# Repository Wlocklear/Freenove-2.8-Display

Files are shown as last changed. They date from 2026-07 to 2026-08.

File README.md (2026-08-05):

# Freenove ESP32-S3 2.8" (CYD) Display Case — v1.0

A closed, tilted desktop enclosure for the Freenove ESP32-S3 2.8" capacitive-touch
display (ESP32-2432S028R "CYD"). Two printed parts that bolt together with 4 M3 screws.

## Parts

| File | What | Print orientation |
|---|---|---|
| `exports/front_panel.stl` | Lid: LCD window, bevel, mic hole, 4 board standoffs, speaker-grille side | Flat, **screen-face down** |
| `exports/base.stl` | Closed tub: side walls (USB-C mount on the left, speaker mount on the right), full back wall, roof, 2 posts + 2 bosses | **Standing on its back wall** (roof/floor print as vertical walls, no support) |

`case.py` (build123d) generates the real, printable parts into `exports/`. `case.3mf` /
`.glb` are the assembled model; open `viewer.html` (served over localhost) to inspect
it in 3D. Any *test/validation coupon* -- a small carved-out piece printed to check a
fit before committing to a full part -- exports into `exports/coupons/` instead, never
the `exports/` root. `usbc_coupon.py` carves a small test coupon of just the USB-C
mount; `speaker_coupon.py` carves a small test plaque of the speaker retention mount
(ledge + clips + grille); `display_coupon.py` carves the front-panel patch around the
4 board standoffs + LCD window + mic hole to test the board mount.

### Layout

```
case.py, *_coupon.py, viewer.html            CAD source + viewer
README.md, CHANGELOG.md                        docs
exports/           real, printable parts (STL / 3MF / GLB, generated)
exports/coupons/    test/validation coupons only (generated) -- standard convention,
                    keep small fit-test pieces out of the exports/ root
images/     renders & diagrams
photos/     real-world build photos
_incoming/  unsorted uploads to be filed
scratch/    local experiments (gitignored)
```

## Key dimensions

- Panel **105 tall × 87 wide × 3 thick**, LCD window **60 × 46**, tilt **60°** from horizontal
- Board on 4 standoffs (Ø6, 78 × 42 pattern), dropped 3 mm to center the active area
- **Mic** hole Ø2 (chamfered) 6 mm from the top-right mount
- **Speaker** (40.3 × 28.3 × 9.8): sits flush against the **right** side wall over an
  11-slot grille, held by a bottom ledge (shelf + lip) and 2 corner snap clips at the top
- **USB-C** panel-mount on the **left** side wall (wall_R), centered on the wall: 9 × 3
  cutout, 2 holes 15 mm apart
- Assembly: **4 × M3** from the front (2 bottom posts + 2 top bosses), self-tapping

## Printing notes

- Suggested: **3 perimeters**, 15% infill (part is wall-dominated; infill barely matters,
  extra perimeters strengthen the self-tapping screw bosses)
- **`HOLE_COMP = 0.4`** in `case.py` oversizes every screw/mount hole to counter this
  printer's ~0.4 mm hole shrinkage. If screws come out loose lower it; if tight, raise it.
- Regenerate after any change: `python case.py`

## Assembly

1. Slide the speaker onto the base's ledge (right side wall) and press the top edge
   past the 2 corner clips until it snaps in, over the grille.
2. Mount the CYD board on the 4 standoffs.
3. Fit the USB-C panel-mount into the left side wall (2 screws).
4. Seat the panel onto the tub and drive the 4 M3 corner screws from the front.

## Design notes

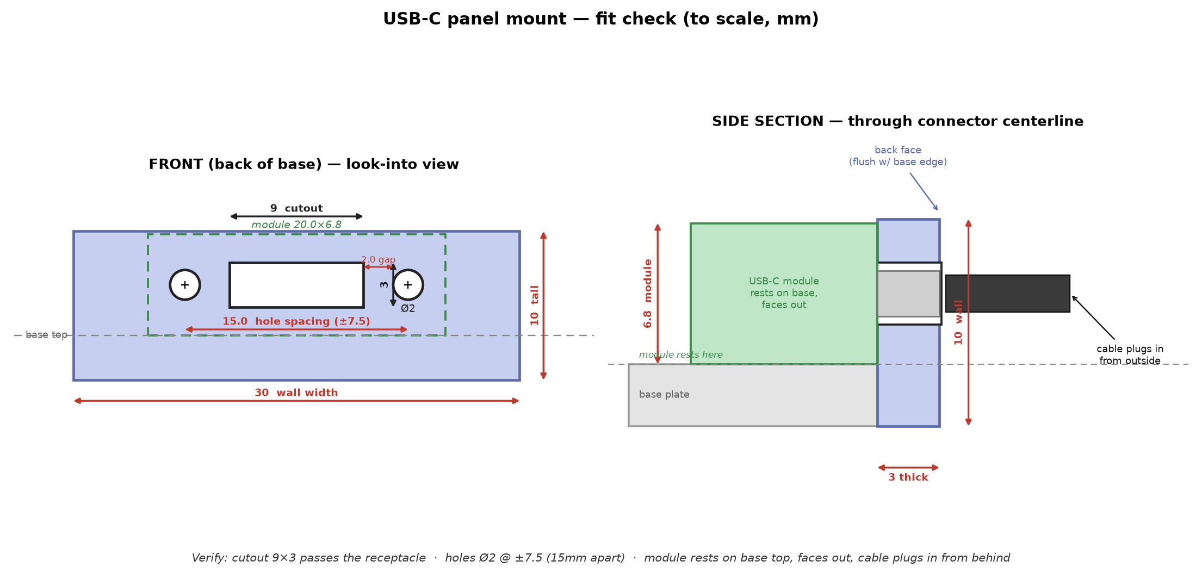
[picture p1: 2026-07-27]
images/usbc_slice.png

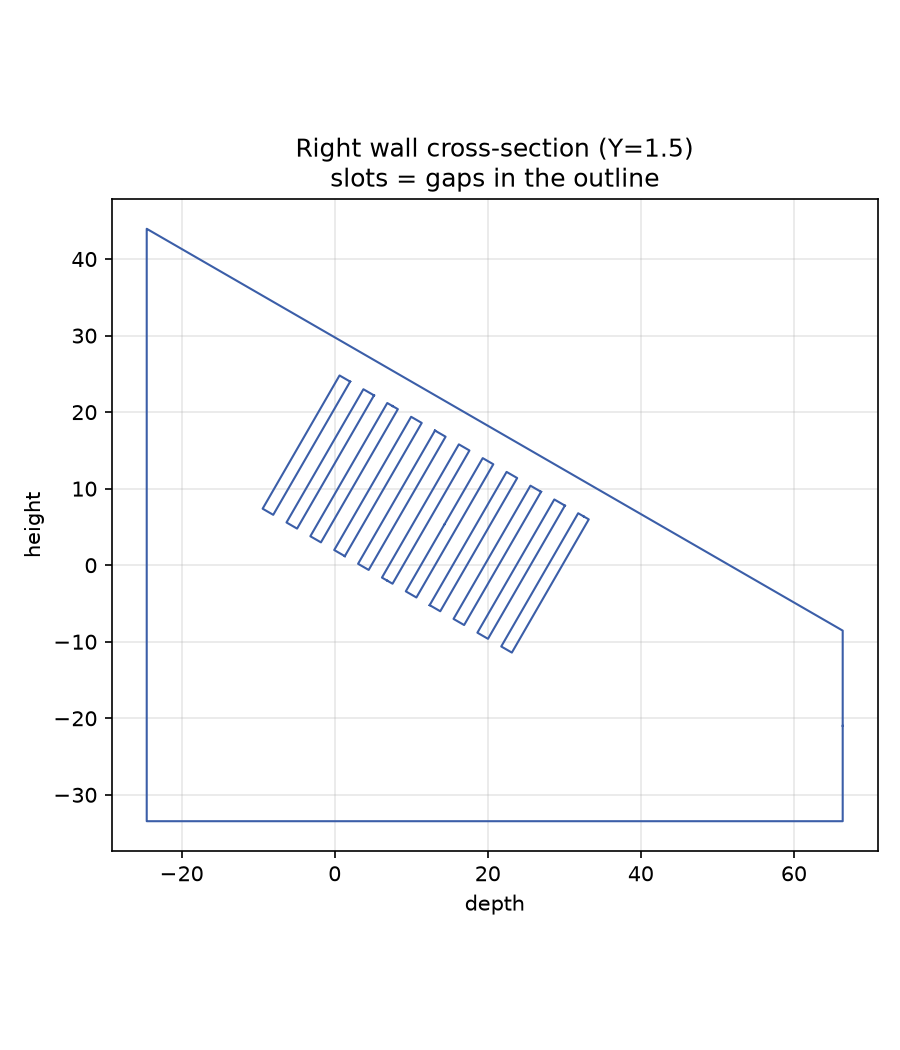
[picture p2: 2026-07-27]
images/speaker_wall_section.png

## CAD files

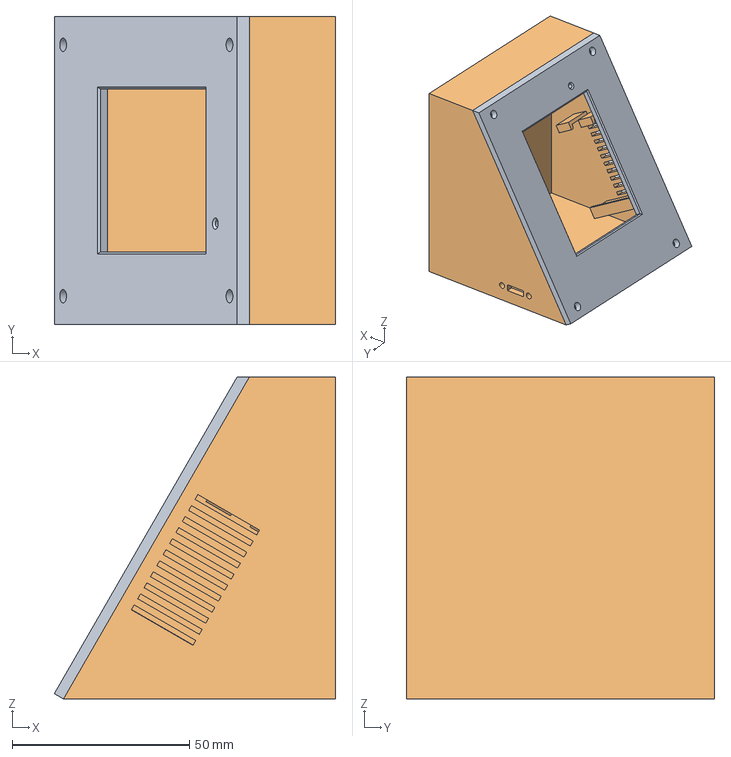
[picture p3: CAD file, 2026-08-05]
exports/case.3mf
79.5 x 87.0 x 90.9 mm
front_panel
base

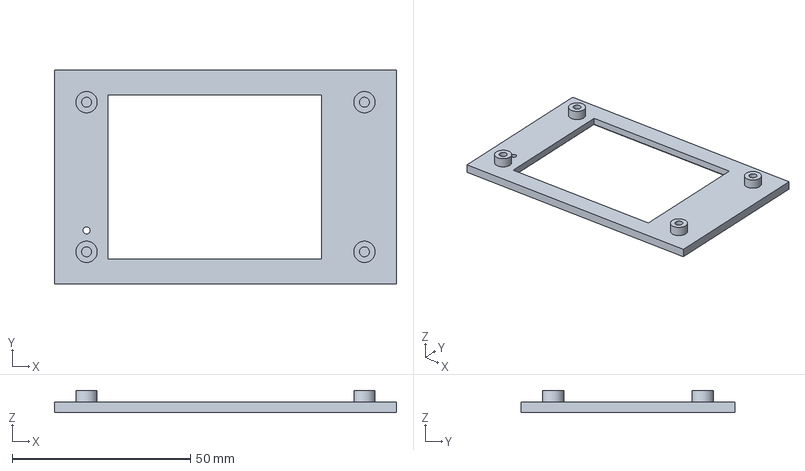
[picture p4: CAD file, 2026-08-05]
exports/coupons/display_coupon.3mf
96.0 x 60.0 x 6.30 mm

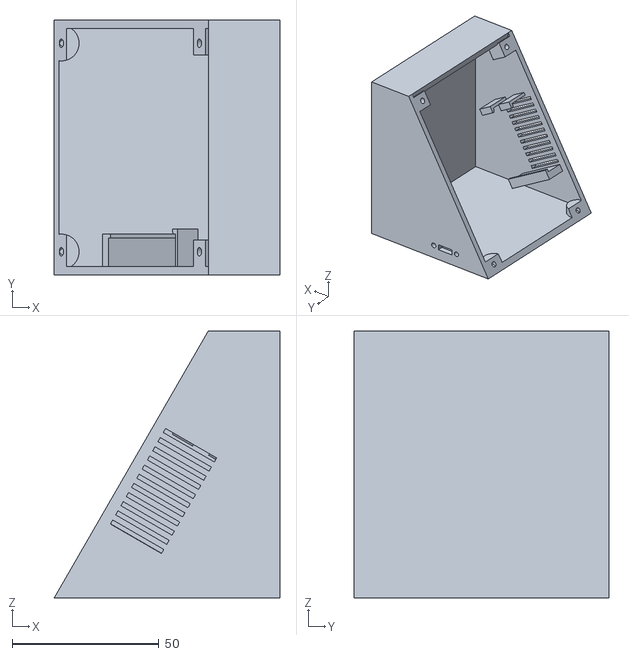
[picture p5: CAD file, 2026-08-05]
exports/base.stl
76.9 x 87.0 x 90.9

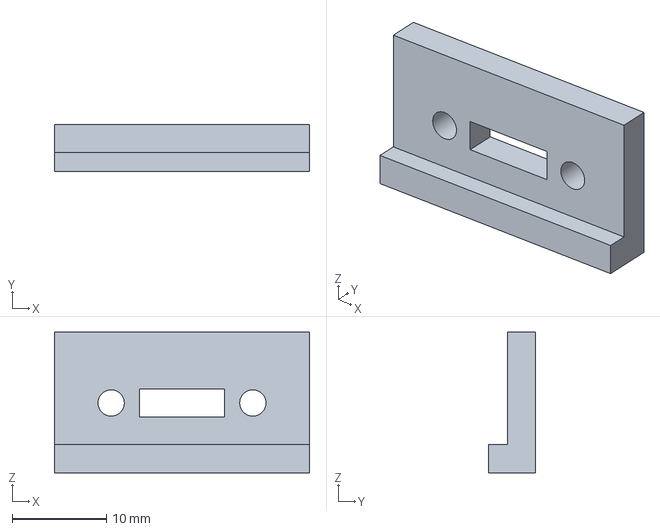
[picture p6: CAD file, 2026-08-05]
exports/coupons/usbc_coupon.3mf
27.0 x 5.00 x 14.9 mm

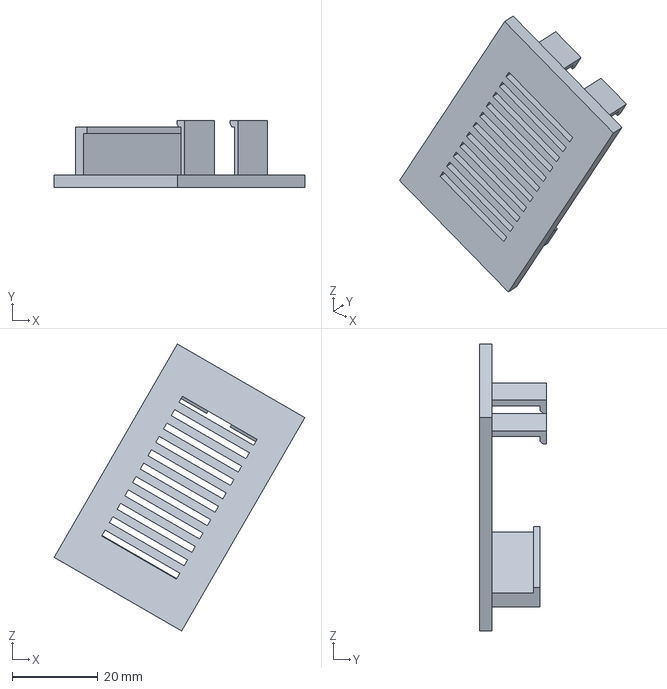
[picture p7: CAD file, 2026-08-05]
exports/coupons/Freenove_Speaker_Coupon.3mf
58.4 x 15.7 x 66.9 mm

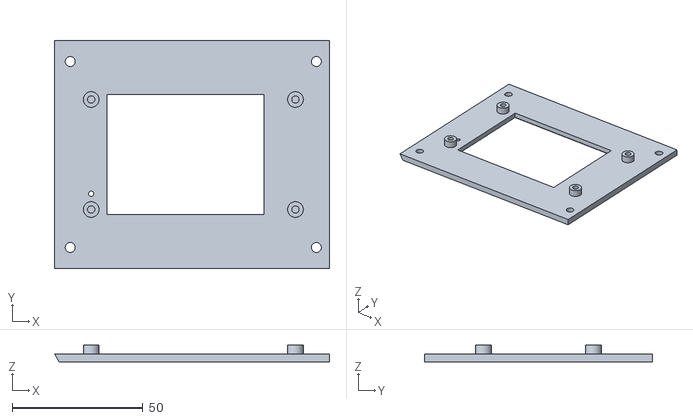
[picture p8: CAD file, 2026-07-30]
exports/front_panel.stl
105.0 x 87.0 x 6.30

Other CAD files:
exports/coupons/Freenove_Speaker_Coupon.stl
exports/coupons/display_coupon.stl
exports/coupons/usbc_coupon.stl

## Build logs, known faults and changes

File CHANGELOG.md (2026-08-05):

# Changelog

All notable changes to this enclosure are recorded here.
Format loosely follows [Keep a Changelog](https://keepachangelog.com/);
versions use [Semantic Versioning](https://semver.org/) (MAJOR.MINOR.PATCH).

## [1.0.0] — 2026-08-05

First validated release. Two-part bolt-together enclosure for the Freenove
ESP32-S3 2.8" (CYD) display.

### Added
- **Front panel (lid)** — LCD window 60 × 46, chamfered edge, 4 board standoffs
  (Ø6, 78 × 42 pattern, dropped 3 mm), Ø2 chamfered mic hole 6 mm from the
  top-right mount. Leans 60° from horizontal.
- **Base (closed tub)** — side walls following the panel lean, full-height back
  wall with the USB-C panel-mount (9 × 3 cutout, 2 holes 15 mm apart), and a roof.
  Prints standing on its back wall (no support).
- **4-corner M3 mounting** — 2 bottom posts + 2 top bosses, self-tapping, driven
  from the front; verified collinear with the panel holes at the 60° angle.
- **Speaker mount** — 11-slot grille in the right side wall; speaker held over
  the grille by a bottom ledge + 2 corner snap clips.
- **`HOLE_COMP = 0.4`** — per-printer shrinkage compensation on every screw/mount
  hole so printed sizes match nominal (M3 clearance, self-tap pilots, 3/32" USB-C).
- **Fit-test coupons** (`exports/coupons/`) — `usbc_coupon.py`,
  `speaker_coupon.py`, and `display_coupon.py` carve small printable test
  pieces from the real geometry to validate each fit before a full print.
  `display_coupon.py` covers the front-panel patch around the 4 board
  standoffs, LCD window, and mic hole.

### Notes
- Snap-fit features budget ~0.2–0.4 mm for FDM peg swell / pocket shrink:
  pocket-entering nubs keep ≥0.4 mm side clearance and ~0.5 mm engagement reach.
- Mic hole and speaker slots do not carry `HOLE_COMP`; they print ~0.4 under.

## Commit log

2026-07-27 v1.0 - Freenove ESP32-S3 2.8" display case
    Validated 2-part bolt-together enclosure:
    - front_panel lid (LCD window, mic hole, 4 board standoffs) + base tub
    (side walls, full back wall with USB-C mount, roof)
    - 60 deg tilt, 4x M3 corner mounts (2 posts + 2 top bosses, self-tap)
    - speaker grille in the right side wall; USB-C 15mm-spaced 3/32" holes
    - HOLE_COMP=0.4 shrinkage compensation on all screw/mount holes
    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
    [base.stl, base_plate.3mf, front_panel.stl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]
2026-07-27 chore: reorganize into standard folder structure
    - exports/ (STL/3MF/GLB), images/ (renders), photos/, _incoming/, scratch/
    - scripts now write into exports/; viewer loads exports/base_plate.glb
    - add CHANGELOG.md, .gitattributes; expand .gitignore to standard
    - README documents the layout
    [base.stl, base_plate.3mf, front_panel.stl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]
2026-07-30 fix: trim panel top edge flush with the roof
    The top cut is straight across the panel thickness, so once tilted the screen-face
    corner sat ~1.5mm proud of the back-face corner (which sets the roof height). Slice
    that wedge off so the whole top edge lands level with the roof. Regenerated exports.
    [base_plate.3mf, front_panel.stl]
2026-07-31 refactor: rename base_plate -> case, fix stale OUT export path
    "base_plate" implied a separate part that doesn't exist; the script
    builds both printable parts (front_panel + base tub), so it's now
    case.py. PLATE_W/D/T -> PANEL_W/D/T to match, since they're the front
    panel's dimensions. OUT now resolves relative to the script itself
    instead of a hardcoded path that no longer existed, so regenerating
    writes into this repo's exports/ again.
    [base_plate.3mf, case.3mf]
2026-08-05 Speaker mount + fit-test coupons, reorganized exports/coupons/
    Recovers work that had been committed locally as a disconnected root
    commit (git history lost, file content intact) instead of building on
    bb19abf. Rebased that state onto the real history here; no content lost
    on either side. See CHANGELOG [1.0.0] (updated in place, 2026-08-03).
    Adds the speaker retention mount (ledge + corner snap clips over the
    grille, replacing tape) and a speaker_coupon.py fit-test coupon
    alongside the existing usbc_coupon.py, both now exporting into
    exports/coupons/ instead of exports/ directly.
    [Freenove_Speaker_Coupon.3mf, Freenove_Speaker_Coupon.stl, base.stl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]
2026-08-05 Add display_coupon.py fit-test for the board-standoff panel patch
    [Freenove_Speaker_Coupon.3mf, case.3mf, display_coupon.3mf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]
